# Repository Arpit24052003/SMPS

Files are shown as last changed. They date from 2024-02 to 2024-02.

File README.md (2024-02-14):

# SMPS
Power Supply Unit (PSU) is a vital part in any electronic product design. Most household electronic products like Mobile Chargers, Bluetooth Speakers, Power Banks, Smart Watches etc requires a Power Supply circuit that could convert the AC mains supply to 5V DC to operate them. In this project we will build a similar AC to DC power supply circuit with 10W power rating. That is our circuit will convert the 220V AC mains to 5V and provide a maximum output current upto 2A. This power rating should be enough to power most electronic products running on 5V. Also 5V 2A SMPS circuit is quite popular in electronics since there are lots of microcontrollers which operates on 5V.

The idea of the project is to keep the build as simple as possible, hence we will design the complete circuit over a dotted board (perf board) and will also build our own transformer so that anyone could replicate this design or build similar ones. Excited Right! So lets get started.

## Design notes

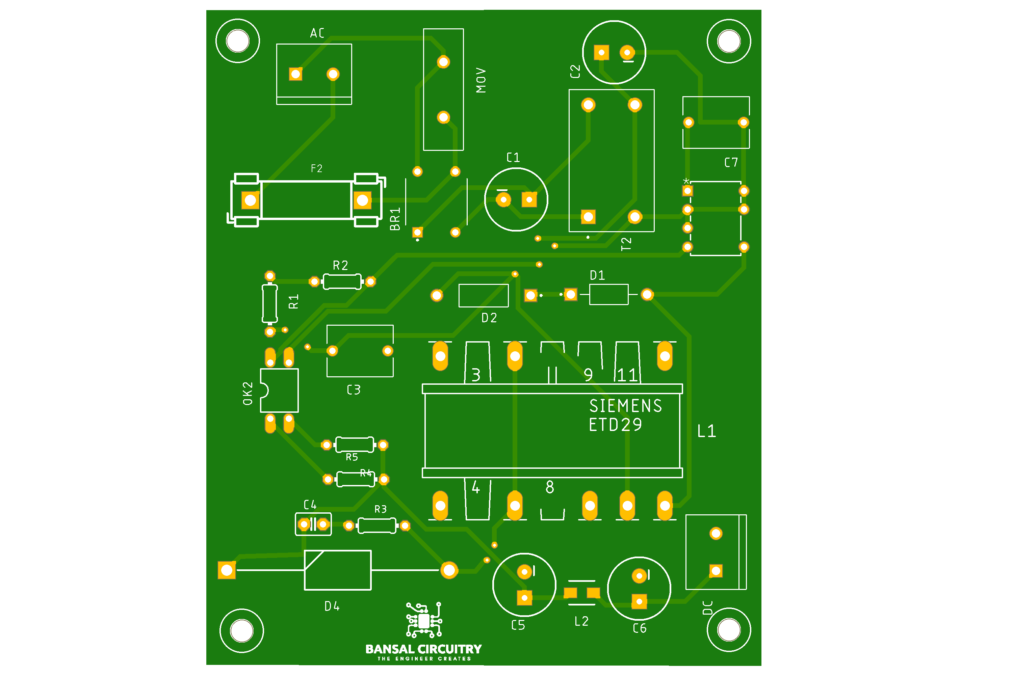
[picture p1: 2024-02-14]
smps top side image.png

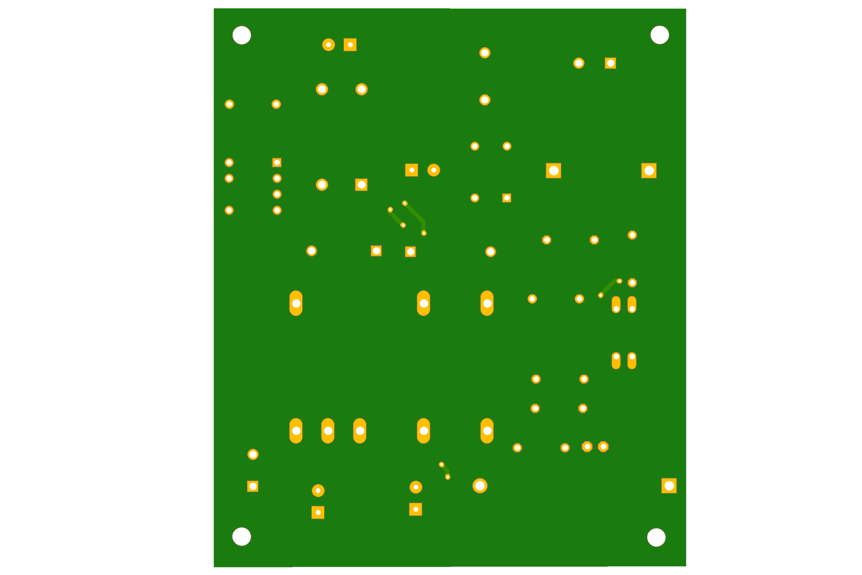
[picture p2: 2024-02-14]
smps bottom side image.png

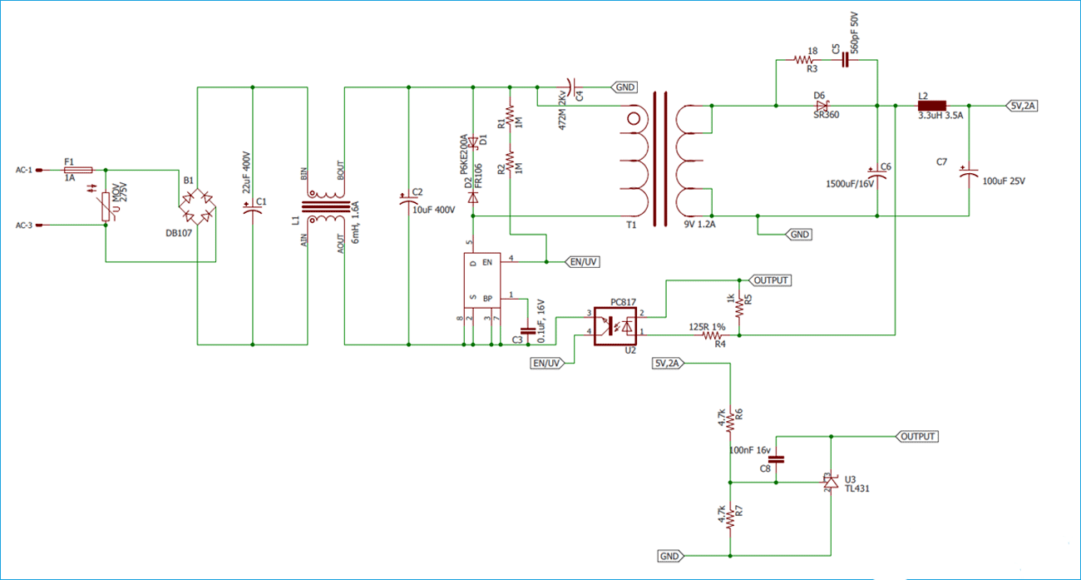
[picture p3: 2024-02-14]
Circuit diagram.png

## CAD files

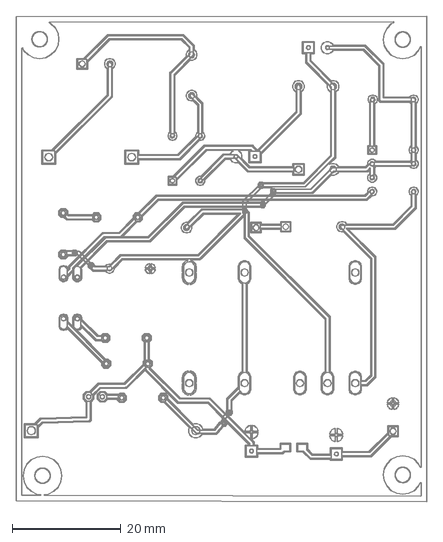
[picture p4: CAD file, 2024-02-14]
spms.dxf
75.3 x 89.1 mm

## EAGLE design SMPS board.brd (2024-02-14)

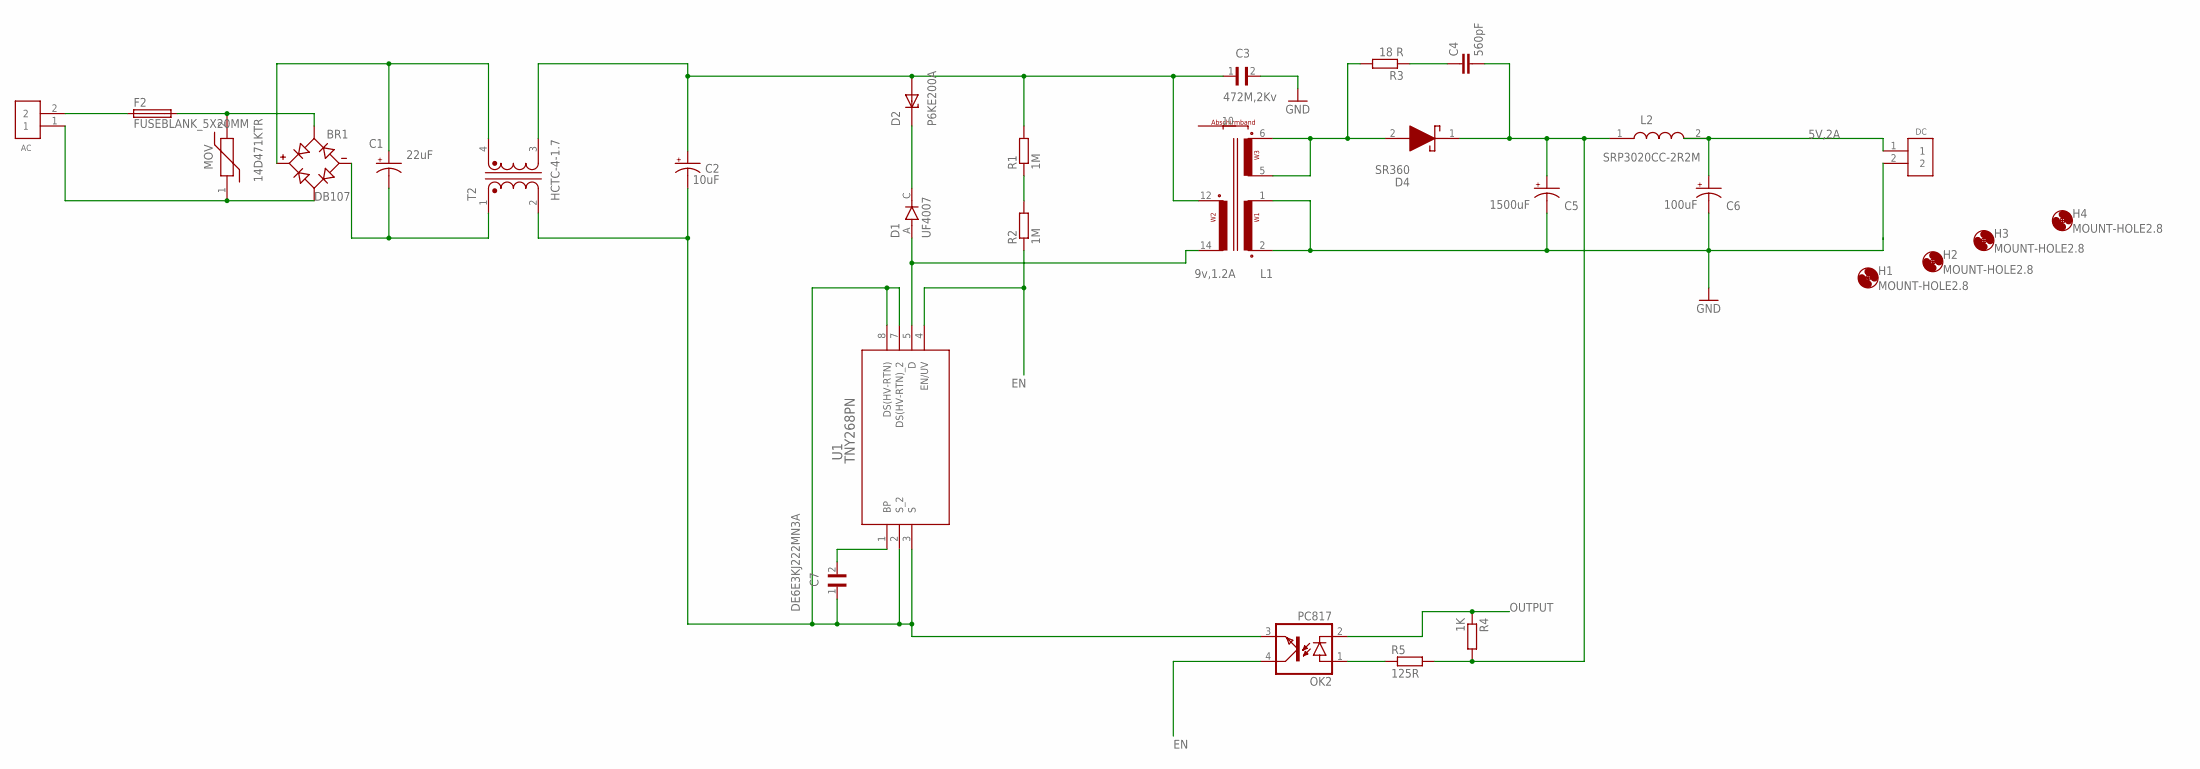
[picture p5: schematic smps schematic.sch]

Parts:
AC: 282837-2; TE_282837-2
BR1: DB107; DIP825W50P509L880H320Q4
C1: 22uF; CPOL-RADIAL-1F-2.7V
C2: 10uF; CPOL-RADIAL-1F-2.7V
C3: 472M,2Kv; CAP_DE6E3KJ222MN3A
C4: 560pF; C2.5-3
C5: 1500uF; CPOL-RADIAL-1F-2.7V
C6: 100uF; CPOL-RADIAL-1F-2.7V
C7: DE6E3KJ222MN3A; CAP_DE6E3KJ222MN3A
D1: UF4007; DIOAD1036W78L520D274
D2: P6KE200A; DIOAD1276W78L760D360
D4: SR360; DIOAD3020W130L900D530
DC: 282837-2; TE_282837-2
F2: FUSEBLANK_5X20MM; FUSE_HOLDER_5X20MM
H1, H2, H3, H4: MOUNT-HOLE2.8; 2,8
L1: 9v,1.2A; ST-D2
L2: SRP3020CC-2R2M; INDPM3532X200N
MOV: 14D471KTR; MOV14D471K
OK2: PC817; DIL04
R1, R2: 1M; 0204/7
R3: 18 R; 0204/7
R4: 1K; 0204/7
R5: 125R; 0204/7
T2: HCTC-4-1.7; XFMR_HCTC-4-1.7
U1: TNY268PN; PDIP-8B_P_PWI

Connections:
5V,2A: C6.+, DC.1, L2.2
EN: OK2.4 (COL), R2.1, U1.4 (EN/UV)
GND: C3.2, C5.-, C6.-, DC.2, L1.1 (1E), L1.2 (1A)
unnamed: BR1.1 (+), C1.+, T2.4
unnamed: BR1.2 (-), C1.-, T2.1
unnamed: AC.2, F2.1
unnamed: BR1.3 (AC1), F2.2, MOV.2
unnamed: AC.1, BR1.4 (AC2), MOV.1
unnamed: C2.-, C7.1, OK2.3 (EMIT), T2.2, U1.2 (S_2), U1.3 (S), U1.7 (DS(HV-RTN)_2), U1.8 (DS(HV-RTN))
unnamed: R1.1, R2.2
unnamed: C2.+, C3.1, D2.A, L1.12 (2A), R1.2, T2.3
unnamed: D1.C (K), D2.C
unnamed: D1.A, L1.14 (2E), U1.5 (D)
unnamed: C7.2, U1.1 (BP)
unnamed: D4.2 (A), L1.5 (3E), L1.6 (3A), R3.2
unnamed: C4.2, C5.+, D4.1 (K), L2.1, R4.2, R5.2
unnamed: C4.1, R3.1
unnamed: OK2.1 (A), R5.1
OUTPUT: OK2.2 (C), R4.1

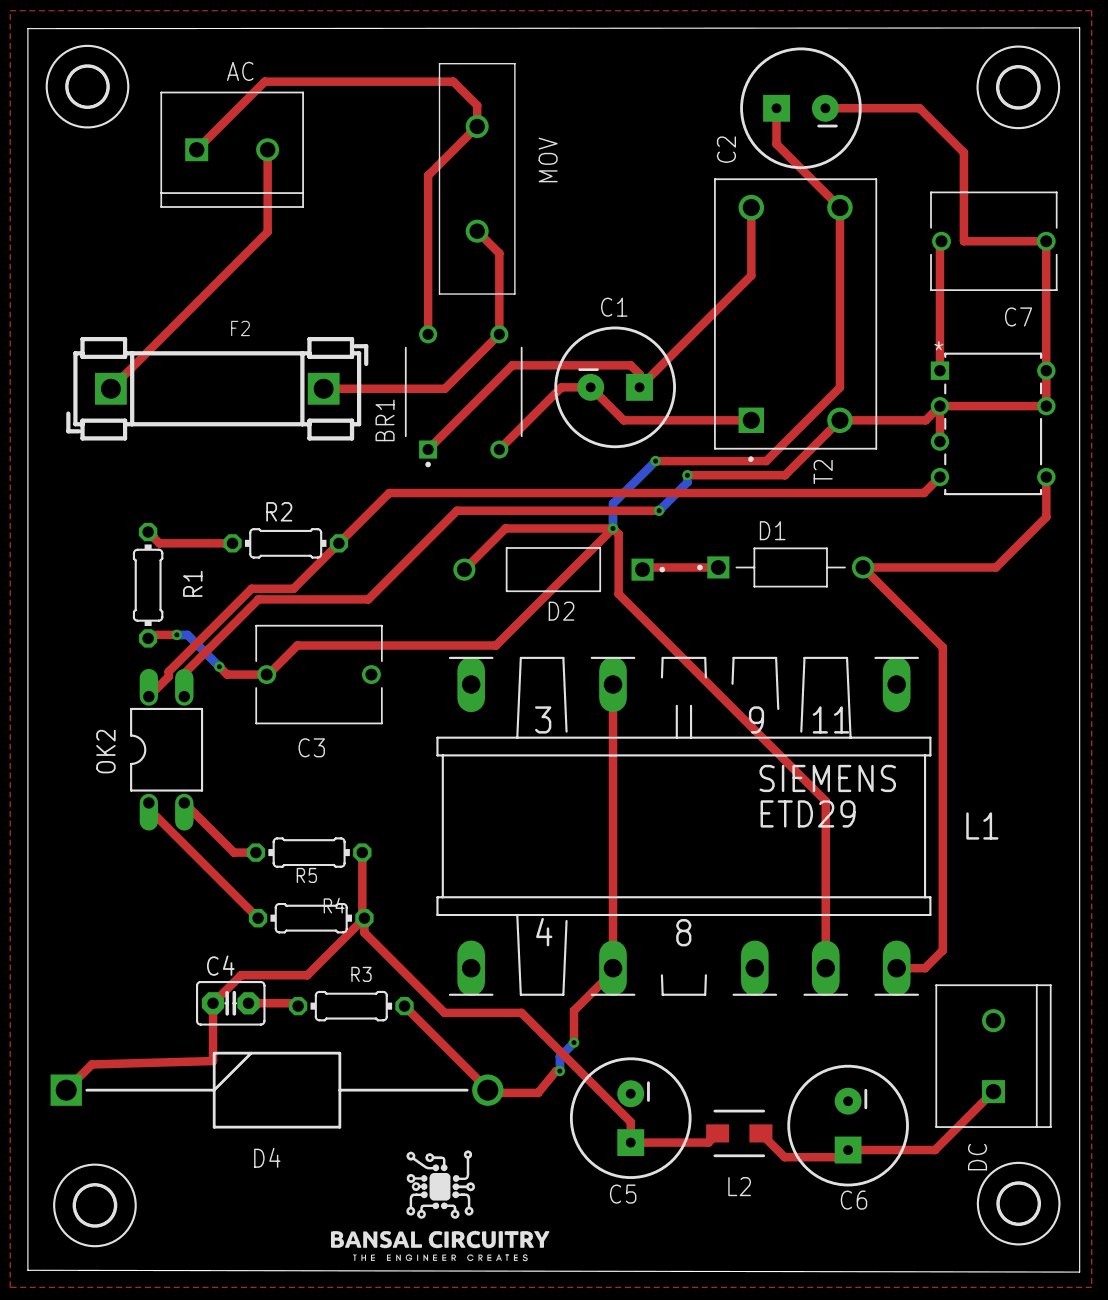
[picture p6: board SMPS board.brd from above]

Board: 2 copper layers, 75.3 x 89.1 mm, 29 parts (0 on the bottom side), 19 nets.

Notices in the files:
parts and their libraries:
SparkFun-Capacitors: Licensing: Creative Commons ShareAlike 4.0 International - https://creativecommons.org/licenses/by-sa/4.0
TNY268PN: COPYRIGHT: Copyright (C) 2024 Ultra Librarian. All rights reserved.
